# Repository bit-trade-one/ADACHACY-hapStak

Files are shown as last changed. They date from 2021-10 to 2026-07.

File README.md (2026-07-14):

# ADCHACY-hapStak

タイトル画像のURLを右のカッコに  
「触感デバイス開発/体感モジュール“hapStak“」は振動アクチュエーターと  
駆動回路がセットになった、振動による触感再現を手軽に扱うためのモジュール。  
フォスター電機が開発した最新のアクチュエーター「FOSTER ACOUSTICHAPTIC®」を採用、  
従来のモジュールにはない「広域振動」「低遅延」「静粛性」の3拍子併せ持った  
万能アクチュエーターとして様々な触感を生み出します。

## [製品の詳細はこちら](https://bit-trade-one.co.jp/hapstak/) 

## [Q&A](https://github.com/bit-trade-one/ADACHACY-hapStak/blob/master/FAQ.md)
　　
# デジタル版　
  

M5StackAtomや、ArduinoMKRZeroからのI2S信号により直接モジュールを駆動する事ができるため、  
コンパクトなデバイス作成が可能です。木製の組立ボードも付属。  

>ご注意！   デジタル版  
>本製品のご使用には別売のマイコンボード及びプログラミング用のPC,更にそれらへの基本的な知識が必要です。
>M5StackAtom端子とArduinoMKRZero端子は排他となり同時に接続できません。

## 端子情報　

  

### [M5 atom のセットアップ方法はこちら](https://qiita.com/eeldog/private/4048234a3f134ed11723)(外部サイトへ遷移）

### [M5 atom を用いた音の鳴らし方](https://qiita.com/eeldog/private/99c412695df9b6c6447c)(外部サイトへ遷移）

### [ArduinoMKRZero を用いた音の鳴らし方](https://qiita.com/eeldog/private/286d1e968b8773e05475)(外部サイトへ遷移）

### [組み立て式ケースの簡易ガイド](https://bit-trade-one.co.jp/hapstakmdfbuild/)(外部サイトへ遷移）

### [サンプルコードはこちら](https://github.com/bit-trade-one/ADACHACY-hapStak/tree/master/Samples)  

### 14種のSignal Patternsを試せる作例はこちら
- [M5Atom Matrix Arduino 1.8.19版](https://github.com/bit-trade-one/ADACHACY-hapStak/tree/master/hapStakDemo)  
- [M5Atom Matrix / S3 /S3R PlatformIO版](https://github.com/bit-trade-one/ADACHACY-hapStak/tree/master/hapStakDemo2)

### [変換ツールはこちら](https://github.com/bit-trade-one/ADACHACY-hapStak/tree/master/converter)  

### [付属ケースデータ](https://github.com/bit-trade-one/ADACHACY-hapStak/tree/master/svg)　　

### [回路図・基板図](https://github.com/bit-trade-one/ADACHACY-hapStak/tree/master/Schematics/digital)　

### [3Dプリント用ケース配布](https://github.com/bit-trade-one/ADACHACY-hapStak/tree/master/3Dprint_Case)　

### [発展的なデモソース(GNU GPLv3.0)](https://github.com/bit-trade-one/hapstak_3D_DEMO)　

---
　　
# アナログ版　
  
 
  
アンプを搭載しているため、音声信号入力のみでアクチュエータを振動させることが出来ます。　

>ご注意！アナログ版  
>本製品はアクチュエーターと駆動回路がセットになったモジュール製品です。  
>音源を再生する装置はご自身でご用意ください。USB電源端子と電池ボックスからの給電は排他となり同時使用はできません。　

## 端子情報
  　

### [回路図・基板図](https://github.com/bit-trade-one/ADACHACY-hapStak/tree/master/Schematics/analog)　

### [サンプル動画①プラコップ](https://youtu.be/OYqQZCnmybw)(外部サイトへ遷移）

### [サンプル動画②バドミントン](https://youtu.be/dnwXpK6lNK8)(外部サイトへ遷移）

---
## 作例
・[特定の方向に引っ張られているかのような錯覚を起こすサンプル](https://github.com/stake2722/HapStak_Pullusion/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) (stake2722様作)

[「ｈ.tanaka」様 /](https://x.com/hide63414/status/1664280147862884352?s=61&t=K7_oe2BjRKS2lTFRml1X2A)

---
## 製品仕様
基本仕様
 
【搭載アクチュエーター】フォスター電機 ACOUSTICHAPTIC® 639897  
【搭載アンプ】デジタル版：NS4168  
【対応マイコンボード】M5StackAtom/Lite/Matrix/Echo(Echo付属スピーカー発音有）、ArduinoMKRZero  
【必要電力】約1W   
（デジタル版:マイコンボードより供給、アナログ版:USBもしくは付属電池ボックスより供給）  
【本体重量】デジタル版：約 45g (MDF組立時）  
アナログ版：基板 約5g、アクチュエーター 約30g  
【本体サイズ】デジタル版：約 W72×H20×D30mm (MDF組立時）  
アナログ版：約 W25×H10×D25mm （基板のみ、電池ボックス及びアクチュエーターを除く）  
【付属品】MDF Stacking Board（デジタル版のみ）、電池ボックス（アナログ版のみ）、保証書  
【パッケージサイズ】F-8 チャック袋梱包　約170*120*20mm  
【使用温度】 0 ～ 40℃（結露なきこと）  
【保証期間】1年間  
【生産国】Made in Japan

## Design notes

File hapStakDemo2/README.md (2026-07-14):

# ADACHACY - hapStakDemo

触感デバイス開発モジュール **hapStak** と M5Stack ATOMシリーズの構成で、14種のSignal Patterns（触覚振動）を試せるデモプログラムです。

本バージョンは旧Arduino IDE版（M5Atomライブラリ + ESP32ボード1.0.6）を全面的に更新したものです。
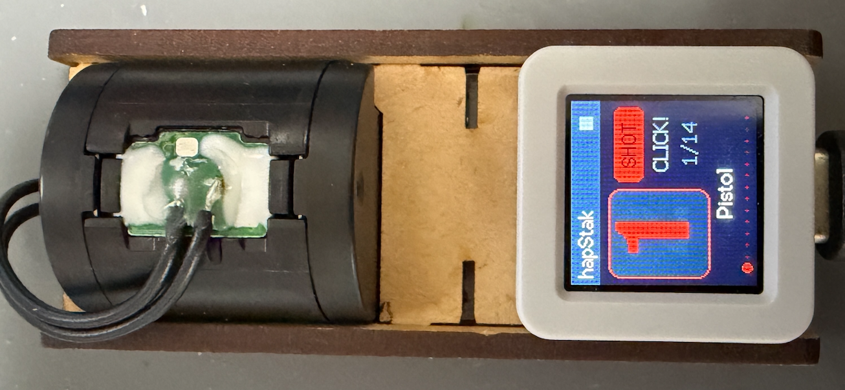
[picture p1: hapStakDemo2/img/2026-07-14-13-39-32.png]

## 対応ハードウェア

| ボード | SoC | 表示 | ビルド環境名 |
|---|---|---|---|
| ATOM Matrix | ESP32 | 5x5 LEDマトリクス | `m5stack-atom` |
| AtomS3 | ESP32-S3 | 128x128 LCD GUI | `m5stack-atoms3` |
| AtomS3R | ESP32-S3 | 128x128 LCD GUI | `m5stack-atoms3` |

AtomS3とAtomS3R（IMU: MPU6886 / BMI270 の違い等）は、**M5Unifiedが実行時に自動判別**するため同一ファームウェアで動作します。

## 旧版からの変更点

- **PlatformIOプロジェクト化** — Arduino IDEのバージョン固定（ESP32 1.0.6 / M5Atom 0.0.9）が不要になりました
- **M5Unified対応** — ATOM Matrix / AtomS3 / AtomS3R を1つのコードでサポート
- **WAVデータのフラッシュ埋め込み再生（PROGMEM）** — SPIFFSへの書き込みが不要になり、旧版の「`WRITEFILES 1`で書き込み→`0`に戻して再書き込み」という2段階手順を撤廃。**1回の書き込みだけで動作します**
- **AtomS3/S3R用のLCD GUI** — トラック番号・カテゴリ・信号名・再生アニメーションを表示

## ファイルリスト

- `README.md` — 本ドキュメント
- `TESTING.md` — テスト一覧（期待動作・各Signalの意味の一覧）
- `LICENSE.txt` — ライセンス条項（GPLv3）
- `hapStakDemo Instruction.pdf` — 使用方法（旧版の手順書。操作方法の参考）
- `platformio.ini` — PlatformIOプロジェクト設定
- `src/main.cpp` — メインプログラム
- `src/ui.h` / `src/ui_matrix.cpp` / `src/ui_lcd.cpp` — 表示処理（LEDマトリクス / LCD GUI）
- `src/AudioGeneratorWAVRepeatable.{h,cpp}` — シームレスループ再生対応WAVジェネレータ
- `src/wav/*.h` — 振動波形データ（C配列化されたWAV）

## ビルドとインストール

[PlatformIO](https://platformio.org/)（VSCode拡張 または CLI）が必要です。ライブラリ（M5Unified / ESP8266Audio / FastLED）は初回ビルド時に自動でインストールされます。

```sh
# AtomS3 / AtomS3R
pio run -e m5stack-atoms3 -t upload

# ATOM Matrix
pio run -e m5stack-atom -t upload

# シリアルモニタ (115200bps)
pio device monitor
```

> **Note (AtomS3/S3R):** 書き込みに失敗する場合は、本体側面のリセットボタンを緑色LEDが点灯するまで（約2秒）長押ししてダウンロードモードに入れてから書き込んでください。

## 使用方法

1. hapStakモジュールをATOM裏面のソケットに接続し、Atom TailBatまたはUSB-Cから給電すると起動音が鳴りStandby状態になります（起動画面 → Signal 1の表示）。
2. Trigger Switch（ATOM Matrix: 画面パネル / AtomS3系: 画面）で操作します。

| 操作 | 動作 |
|---|---|
| 短押し（クリック） | One Shot: 振動を1回発振 / LOOP: 再生・停止の切り替え（フェードイン・アウト付き） |
| 本体を振る（約3G以上） | Swing: 振動を1回発振 |
| 長押し（約0.3秒） | 次のSignalへ切り替え |
| 長押し（約1秒） | Action Categoryごとにスキップ（One Shot → Swing → LOOP → …） |
| トリプルクリック | Signal 1に戻る |

### 画面表示

**ATOM Matrix（5x5 LED）**
- Signal番号を表示（色はAction Category: One Shot=赤 / Swing=緑 / LOOP=青）
- 右下LED: 再生中（白点灯）
- 右上LED: エラー（赤点灯）

**AtomS3 / AtomS3R（LCD GUI）**
- 起動時: スプラッシュ画面（機種名を自動表示）
- Signal番号（カテゴリ色）／カテゴリチップ（SHOT / SWING / LOOP）
- 信号名（Pistol、Heart Beat等）とトリガーヒント（CLICK! / SHAKE! / REPEAT）
- 14トラックのポジションドット、再生中はイコライザ風アニメーション

## Signal Patterns 仕様

全波形とも **モノラル / 8bit PCM / 8kHz** のWAVデータです。起動音のみ16kHzです。

### One Shot（クリックで1回発振・赤）

| No. | 信号名 | 長さ | データ |
|---|---|---|---|
| 1 | Pistol | 1.5秒 | `file07.h` |
| 2 | Machine Gun | 2.0秒 | `file08.h` |
| 3 | Bazooka | 3.3秒 | `file09.h` |

### Swing（振ると1回発振・緑）

| No. | 信号名 | 長さ | データ |
|---|---|---|---|
| 4 | Tennis | 0.2秒 | `file10.h` |
| 5 | Wooden Bat | 1.4秒 | `file11.h` |
| 6 | Iron Bat | 0.9秒 | `file12.h` |
| 7 | Sword Slash (Blank) | 0.5秒 | `file13.h` |
| 8 | Sword Slash (Object) | 0.3秒 | `file14.h` |

### LOOP（選択中は繰り返し発振・青）

| No. | 信号名 | 長さ(1周期) | データ |
|---|---|---|---|
| 9 | Low Vibe (60Hz) | 0.1秒 | `file01.h` |
| A | Crispy Pulse | 0.08秒 | `file02.h` |
| B | Up Sweep | 0.5秒 | `file03.h` |
| C | Alpha Wave (60Hz) | 10秒 | `file04.h` |
| D | Dinosaur Walk | 1.3秒 | `file05.h` |
| E | Heart Beat | 1.8秒 | `file06.h` |

その他: 起動音 = `boot.h`（2.0秒 / 16kHz）。`file15.h` / `file16.h` はLow Vibeの複製（予備・未使用）。

波形の差し替えは、WAVファイルをC配列化した`.h`を`src/wav/`に置き、`src/main.cpp`の`trackData`テーブル（表示番号・信号名・駆動モード・ゲイン・表示色）を書き換えるだけです。

## ピンアサイン（I2S → hapStak）

hapStakモジュールはATOM裏面ソケットに接続します。AtomS3系はATOM Matrixと**物理位置互換**のGPIOを自動選択します。

| 信号 | ATOM Matrix | AtomS3 / AtomS3R |
|---|---|---|
| BCK | G19 | G6 |
| LRCK | G33 | G8 |
| DATA | G22 | G5 |

## 使用ライブラリ

- [M5Unified](https://github.com/m5stack/M5Unified) — ボード自動判別・LCD・IMU・ボタン
- [ESP8266Audio](https://github.com/earlephilhower/ESP8266Audio) by @earlephilhower — I2S WAV再生（Thanks to @earlephilhower!）
- [FastLED](https://github.com/FastLED/FastLED) — ATOM MatrixのLED表示

## ライセンス

GPLv3 — 詳細は`LICENSE.txt`を参照してください。
Copyright (C) 2021 Foster Electric Co., Ltd.

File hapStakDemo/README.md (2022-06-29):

# ADCHACY - hapStakDemo インストール方法

## はじめに
本作例では、触感デバイス開発モジュールとM5Atom Matrixの構成で、14種のSignal Patternsを試すことができます。

## ファイルリスト
- README.md [本ドキュメント]
- LICENSE.txt[ライセンス条項]
- hapStakDemo Instruction.pdf［使用方法］
- hapStakDemo.ino[サンプルプログラム]
- AudioGeneratorWAVRepeatable.cpp[サンプルプログラム]
- AudioGeneratorWAVRepeatable.h[サンプルプログラム]
- wav/*.h[サンプル音源]

## 前提条件
本作例の動作を確認済みの環境は以下になります。
- Arduino IDE 1.8.19（Windows版）
- ESP32ボードライブラリ 1.0.6
- M5Atomライブラリ 0.0.9
- [ESP8266Audio 1.9.5](https://github.com/earlephilhower/ESP8266Audio/tree/1.9.5) [@earlephilhower氏の
ESP8266Audioライブラリを使用させていただきました。]<BR>
Thanks to  @earlephilhower, author of the ESP8266Audio library.

## 注意事項
　2022年6月現在、最新のArduinoのライブラリでは本サンプルソフトの正常なビルドおよび動作が確認できておりません。指定のバージョンのライブラリをインストールした環境を推奨します。

## インストール方法　
- ボードマネージャのインストール<BR>
「ESP32 by Espressif Systems バージョン1.0.6」をインストールします。
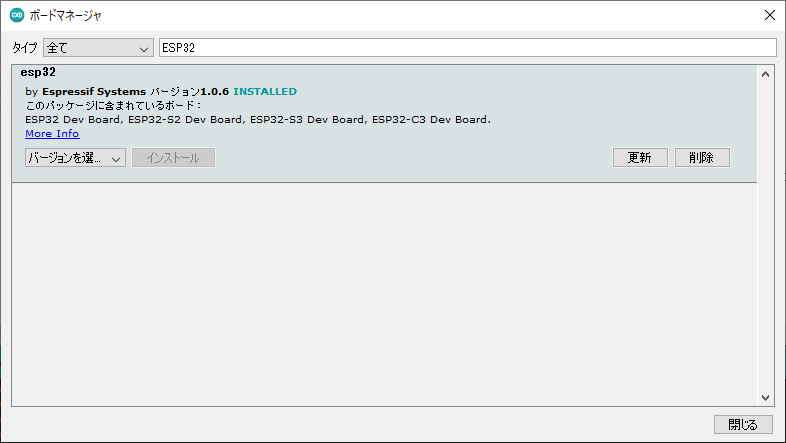
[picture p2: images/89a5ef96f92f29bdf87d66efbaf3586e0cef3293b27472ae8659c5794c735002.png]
  

- M5Atomライブラリのインストール<BR>
「ツール」「ライブラリを管理」からライブラリマネージャを開き、「M5Atom by M5Stack バージョン0.0.9」をインストールします。
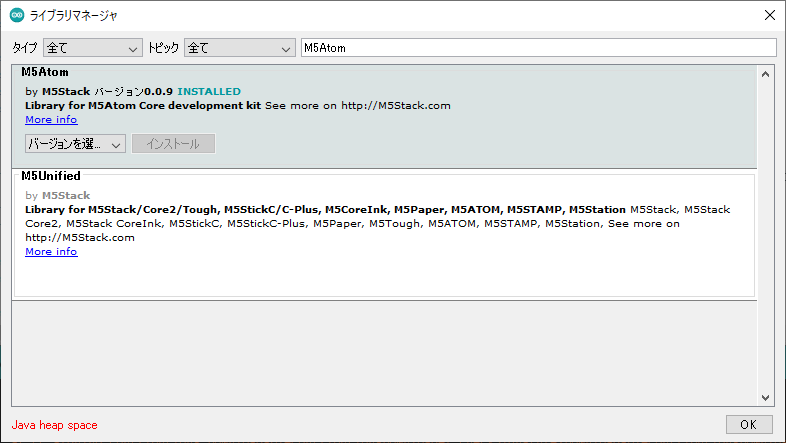
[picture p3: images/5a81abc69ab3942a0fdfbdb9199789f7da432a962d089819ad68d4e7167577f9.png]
  

- ESP8266Audioライブラリ<BR>
GitHubからzip形式でダウンロード後、Arduino IDEの「スケッチ」「ライブラリをインクルード」「.ZIP形式のライブラリをインストール」を選択し、ダウンロードしたzipファイルを指定します。
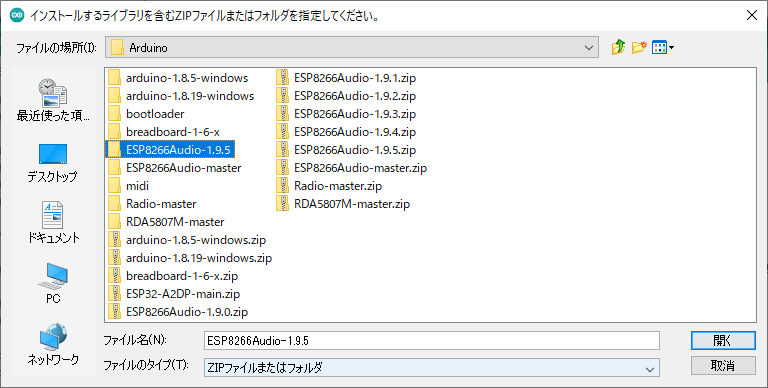
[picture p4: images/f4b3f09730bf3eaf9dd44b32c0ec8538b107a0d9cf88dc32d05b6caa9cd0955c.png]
  

- hapStakDemo<BR>
Arduino IDEの「ファイル」「開く」から予めダウンロード済みの「hapStakDemo.ino」を指定します。
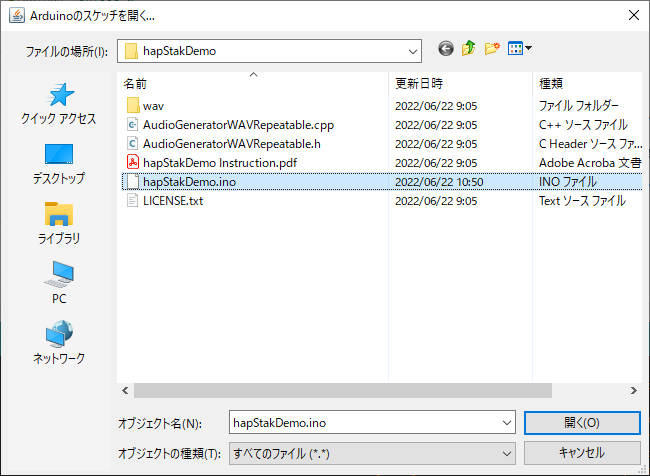
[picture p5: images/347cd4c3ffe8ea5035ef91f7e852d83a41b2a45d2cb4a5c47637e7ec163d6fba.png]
  

- Arduino IDEの設定<BR>
「ツール」メニューから「ボード」は「M5Stack-ATOM」、「シリアルポート」は接続したCOM番号を指定します。
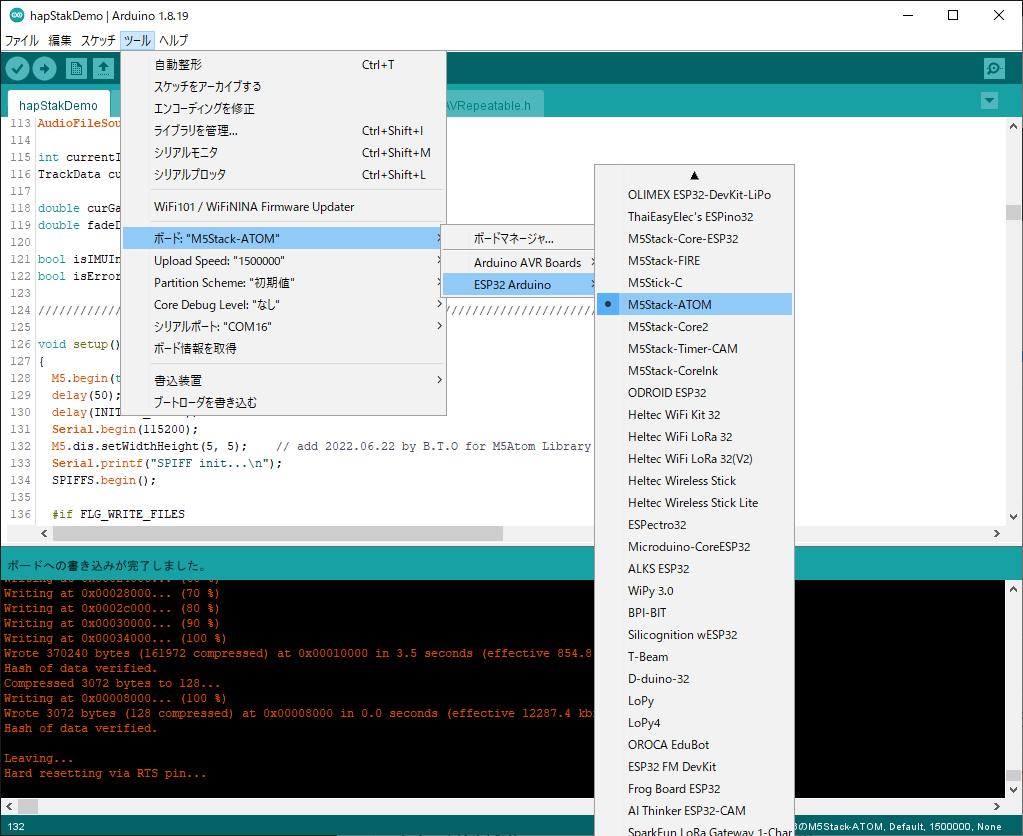
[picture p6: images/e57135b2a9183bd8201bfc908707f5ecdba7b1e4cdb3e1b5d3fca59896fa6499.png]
  

- ビルドとインストール<BR>
「スケッチ」「マイコンボードに書き込む」からビルドとインストールを実施します。以降は、[HapStackDemo Instruction](https://github.com/bit-trade-one/ADACHACY-hapStak/blob/master/hapStakDemo/hapStakDemo%20Instruction.pdf)に従ってください。

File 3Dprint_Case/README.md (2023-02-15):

# filelist

- README.md
  - 本ファイル
- hapStak_3D_20220802 v1.stl
  - STLファイル。Github上でプレビュー可能です
- hapStak_3D_20220802.stp
  - STEPファイル

# 本体写真







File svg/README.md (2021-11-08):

##  [MDFケースの簡易組立ガイドはこちら](https://bit-trade-one.co.jp/hapstakmdfbuild/)(外部サイトへ遷移）

## 展開図 
### [ADACHA_digital_Housing.png](https://github.com/bit-trade-one/ADACHACY-hapStak/blob/master/svg/ADACHA_digital_Housing.png)　 
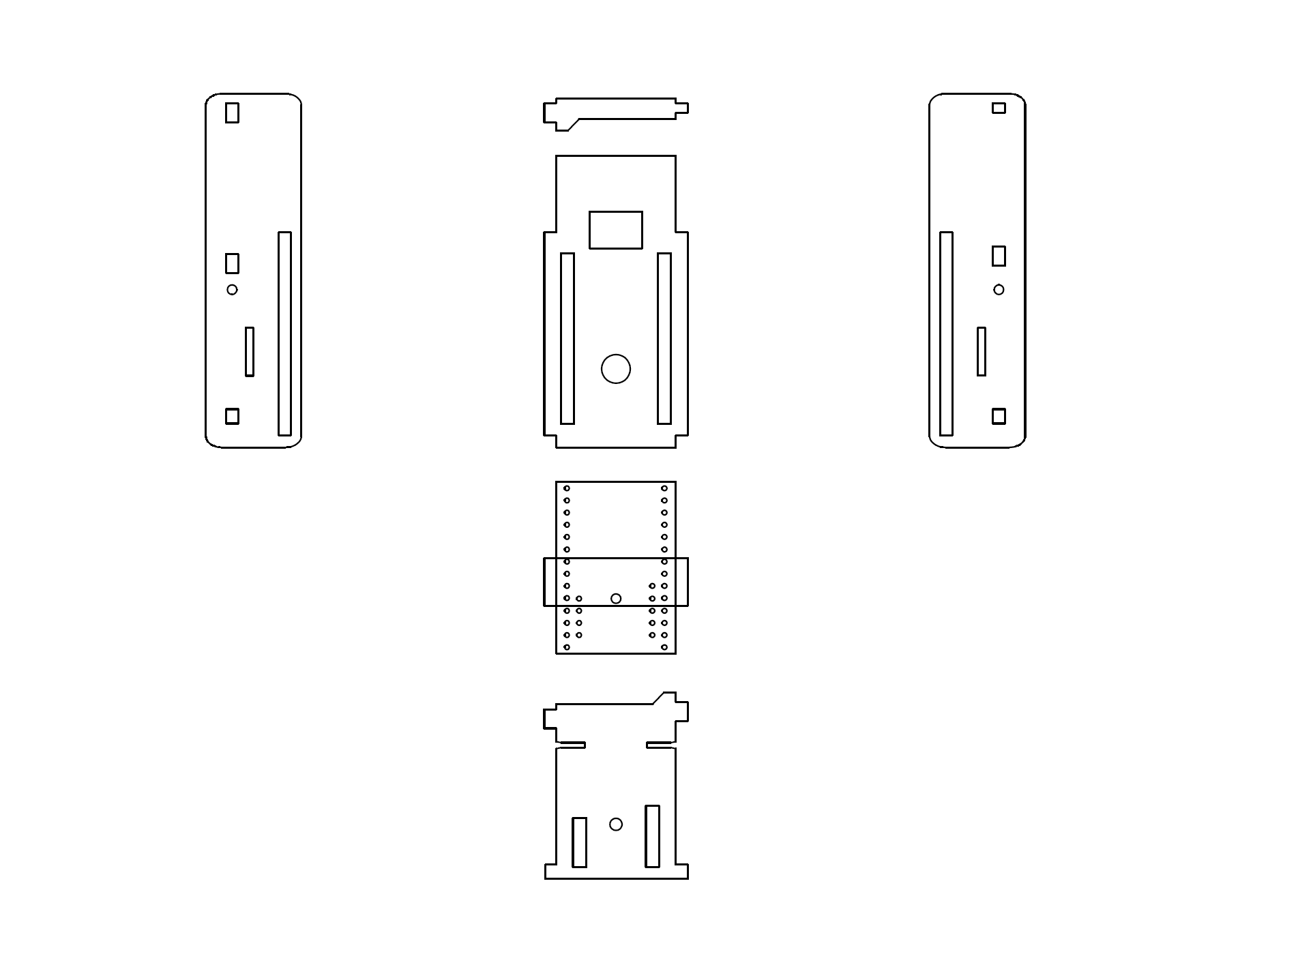
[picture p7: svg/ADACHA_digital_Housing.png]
  
  
## svgが必要な場合はこちらをお使いください。  
###  [hapStak_v100L3c2p5k5L.svg](https://github.com/bit-trade-one/ADACHACY-hapStak/blob/master/svg/hapStak_v100L3c2p5k5L.svg)

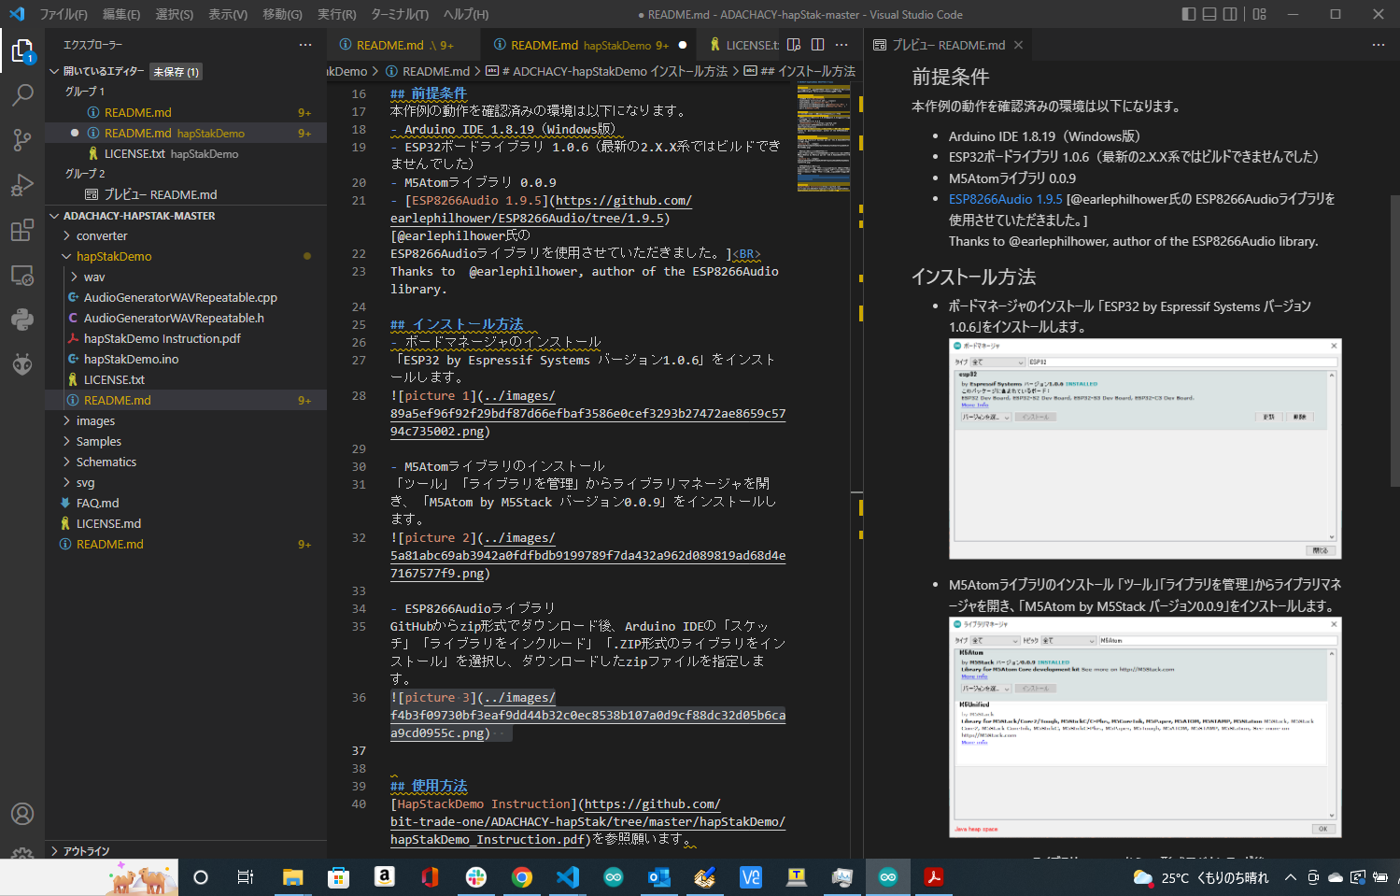
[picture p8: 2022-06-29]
images/1d6149066ba7110dcfcefb8596d89483c0a5b277a1b3aa42a23163144236d40b.png

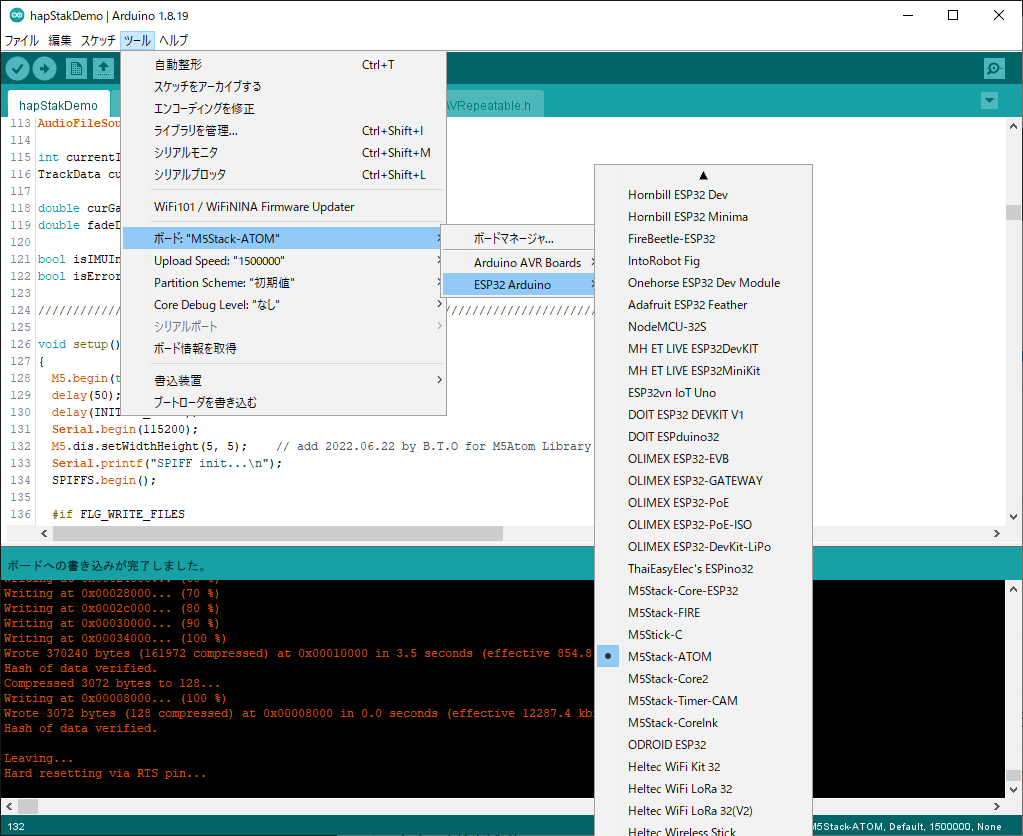
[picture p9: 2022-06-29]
images/1a6300dcdf5a7bfe7124d6cb19e79782b34bdc88744a28cd118b9b9b80bcd5b1.png

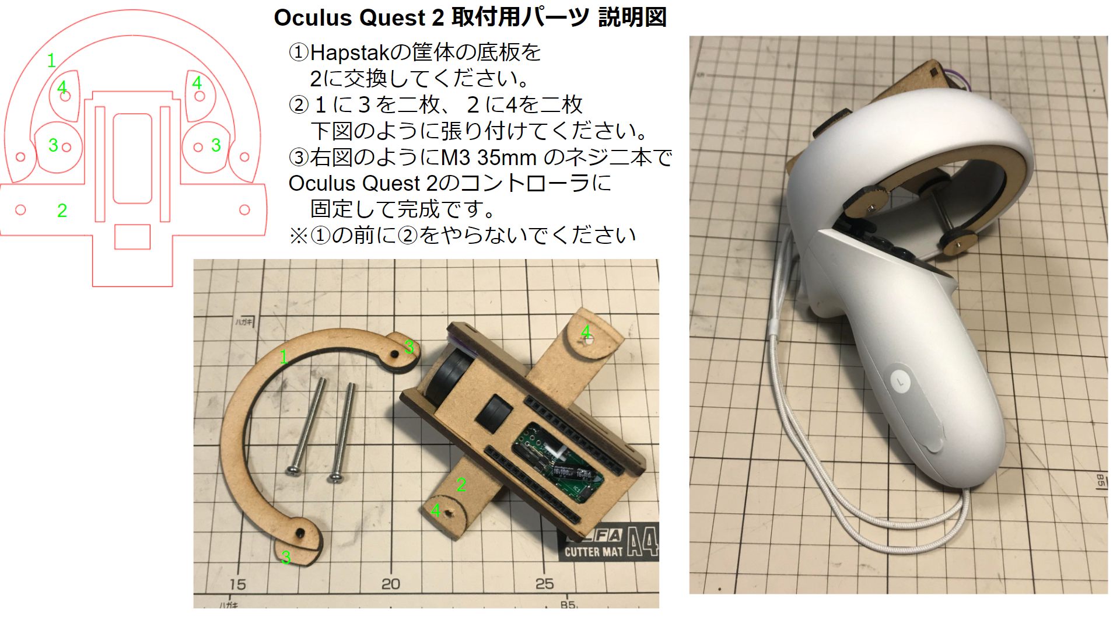
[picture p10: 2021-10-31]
svg/Oculus Quest 2 取付用パーツ 説明図.png

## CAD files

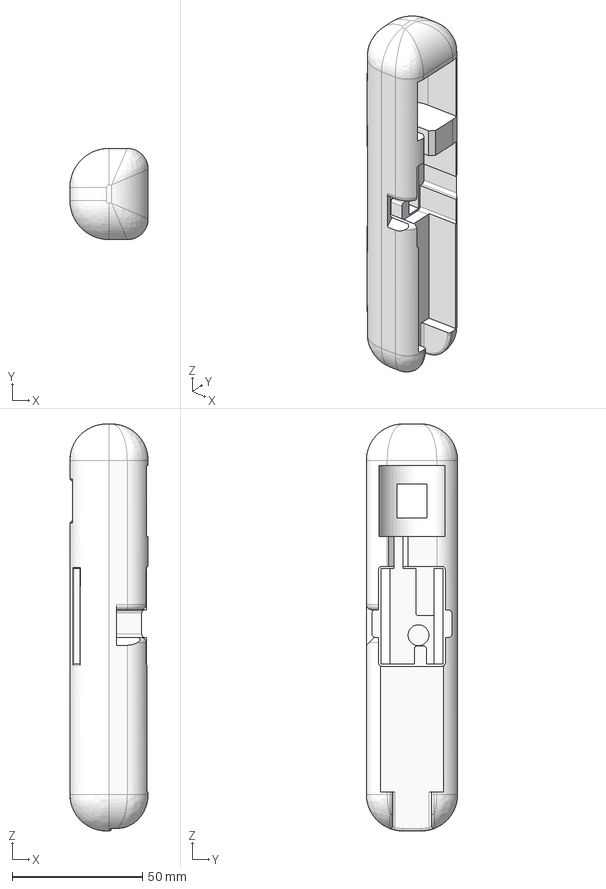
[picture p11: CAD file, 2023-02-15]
3Dprint_Case/hapStak_3D_20220802.stp
30.0 x 35.0 x 156.0 mm

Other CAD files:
3Dprint_Case/hapStak_3D_20220802 v1.stl

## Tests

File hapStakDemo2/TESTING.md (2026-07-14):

# hapStakDemo テスト一覧

各テストの「期待される動作」と一致すればOKです。
シリアルログで確認する場合は `pio device monitor`（115200bps）を使います。

対応機種: ATOM Matrix / AtomS3 / AtomS3R（表示の読み替えは[表示の見方](#5-表示の見方)を参照）

---

## 1. 起動テスト

| # | 手順 | 期待される動作 |
|---|---|---|
| 1-1 | USB-CまたはAtom TailBatから給電する | 起動画面（Matrix: 全LED白点灯 / S3系: hapStakロゴ画面）が出る |
| 1-2 | そのまま待つ | 起動音（約2秒）がhapStakから鳴る |
| 1-3 | 起動音の終了後 | 赤い「**1**」が表示される（= Signal 1選択、無音・無振動で待機） |
| 1-4 | シリアルログ確認（任意） | `IMU: OK` と `SelectTrack:1 Pistol` が出る。`IMU: not found` はNG（Swing不可・エラー表示点灯） |

## 2. Signal一覧と正解動作

「音の意味」= その振動が何を再現しているか。触った/持った手に伝わる感触で確認します。

### One Shot（赤表示・クリックで発振）

**正解動作**: ボタンを**押した瞬間**に1回振動。押すたびに鳴る。振っても鳴らない。

| No. | 名前 | 音（振動）の意味 | 長さ |
|---|---|---|---|
| 1 | Pistol | ピストルの発砲の反動 | 約1.5秒 |
| 2 | Machine Gun | マシンガンの連射の反動 | 約2.0秒 |
| 3 | Bazooka | バズーカ砲の発射 | 約3.3秒 |

### Swing（緑表示・振ると発振）

**正解動作**: 本体を**鋭く振った瞬間**に1回振動。鳴っている間と鳴り終わって0.3秒間は、振っても反応しない（連続発振防止）。クリックでは鳴らない。

| No. | 名前 | 音（振動）の意味 | 長さ |
|---|---|---|---|
| 4 | Tennis | テニスラケットの打球の衝撃 | 約0.2秒 |
| 5 | Wooden Bat | 木製バットの打球 | 約1.4秒 |
| 6 | Iron Bat | 金属バットの打球 | 約0.9秒 |
| 7 | Sword Slash (Blank) | 刀の素振り（空を斬る） | 約0.5秒 |
| 8 | Sword Slash (Object) | 刀で物を斬った手応え | 約0.3秒 |

### LOOP（青表示・自動で繰り返し）

**正解動作**: そのSignalを**選択した瞬間から**フェードインで自動再生され、繰り返し続ける。クリックするとフェードアウトして停止、もう一度クリックすると再開。

| No. | 名前 | 音（振動）の意味 | 1周期 |
|---|---|---|---|
| 9 | Low Vibe (60Hz) | 60Hzの低い連続振動 | 0.1秒 |
| A | Crispy Pulse | カリカリと弾ける短いパルス | 0.08秒 |
| B | Up Sweep | 低→高へ上昇するスイープ | 0.5秒 |
| C | Alpha Wave (60Hz) | 60Hzがゆらぐ持続振動 | 10秒 |
| D | Dinosaur Walk | 恐竜が歩くような重い足音 | 1.3秒 |
| E | Heart Beat | 心臓の鼓動（ドクン、ドクン） | 1.8秒 |

## 3. 操作テスト

| # | 手順 | 期待される動作 |
|---|---|---|
| 3-1 | ボタンを約0.3秒長押し | 次のSignalへ切り替わる（1→2→…→E→1と一巡） |
| 3-2 | ボタンを約1秒長押し | 次のカテゴリの先頭へジャンプ（1〜3で実行→4、4〜8で実行→9、9〜Eで実行→1） |
| 3-3 | 素早く3回クリック（トリプルクリック） | Signal 1に戻る（クリック間隔0.25秒以内） |
| 3-4 | Signal 9〜E選択中に1回クリック | フェードアウトして停止。もう1回クリックで再開 |
| 3-5 | LOOP再生中に0.3秒長押し | 現在の再生が止まり、次のSignalへ切り替わる |

## 4. Swing詳細テスト（Signal 4〜8）

| # | 手順 | 期待される動作 |
|---|---|---|
| 4-1 | 手首のスナップを効かせて鋭く振る | 1回だけ振動する（鳴りっぱなしにならない） |
| 4-2 | 鳴り終わってから再度振る | もう1回鳴る |
| 4-3 | 机に置いたまま・ゆっくり動かす | 鳴らない（閾値3G未満） |
| 4-4 | シリアルログ確認（任意） | 1秒ごとに `accel peak: x.xx G` が出る。静止時は約1.00、振った瞬間に3.00超え |

振っても鳴らない場合: シリアルの `accel peak` が3.00に届いていなければ、振り方が弱いか閾値が高すぎです（`src/main.cpp` の `ACCEL_THRESHOLD` を2.0程度に下げて調整可）。

## 5. 表示の見方

### ATOM Matrix（5x5 LED）

- 数字は**左4列**に表示。色 = カテゴリ（赤=One Shot / 緑=Swing / 青=LOOP）
- **右下**: 再生中のみ白点灯（LOOP選択中はほぼ点きっぱなしで正常）
- **右上**: エラー時のみ赤点灯（**常時消灯が正解**。点灯したらシリアルログを確認）
- 左上に数字と無関係な点灯が居座る場合は表示ずれ（既知の対策済み事象。再発したら報告を）

### AtomS3 / AtomS3R（LCD）

- 大きな数字（カテゴリ色）+ カテゴリチップ（SHOT/SWING/LOOP）+ 信号名
- ヘッダ右: 再生中はイコライザアニメーション、停止中はグレーの■
- ヘッダに赤丸「!」が出たらエラー（常時非表示が正解）
- 下部のドット: 現在のSignal位置（14個中）

## 6. 機種またぎテスト（任意）

| # | 手順 | 期待される動作 |
|---|---|---|
| 6-1 | 同じhapStakをAtomS3/S3Rに付け替えて起動 | 書き込み環境を`m5stack-atoms3`にするだけで同一動作（起動画面に機種名表示） |
| 6-2 | AtomS3Rで起動 | スプラッシュに「AtomS3R」と表示され、IMU（BMI270）でSwingが動く |

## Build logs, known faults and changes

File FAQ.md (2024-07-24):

# ADACHACY-hapStakよくある質問

# 共通

## Q.振動アクチュエータの詳細を教えて下さい
### A.フォスター電機殿のデータシートをご覧ください
https://www.foster.co.jp/products/vibration_actuator/  
フォスター電機 ACOUSTICHAPTIC® 639897が使用している製品です。  

----

# デジタル版 

## Q.notext
 
### A.notext

----

# アナログ版 

## Q.モノラル音源とステレオ音源で振動に違いがありますか

### A.音源内容によりモノラル音源とステレオ音源で振動に違いが出ます

本製品はステレオの入力音源からL/R切り替えジャンパで使用する信号を選択し、選んだ片方の音源を増幅させ振動アクチュエータを駆動させます。

## Q.出力端子のどちらが+ですか？

### A.画像をご参照願います


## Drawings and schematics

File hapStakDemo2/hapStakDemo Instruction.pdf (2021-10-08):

■ Demo Instruction | ■General View

■ Signal patterns

1. Atom TailBatもしくはUSB-Cケーブルより給電すると起動音が発生し、 Standby状態になります。（LED全点灯白 → 1の表示）
2. 下表のAction Categoryに従い触覚信号が駆動します。
3. Trigger Switchを短く(0.3sくらい)長押しするとSignal を切り替えできます。
4. Trigger Switchを長く(1sくらい)長押しするとAction Categoryごとに Skipできます。
5. 選択信号のガイドとして、LEDの表示を参照ください。
6. 給電を停止すると停止します。 (LED 消灯)

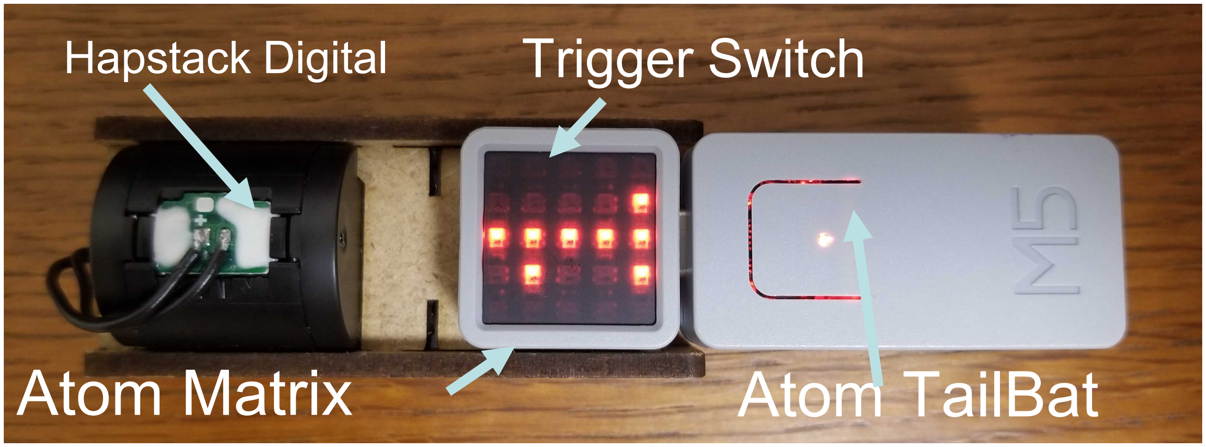
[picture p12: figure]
Trigger Switch; Atom TailBat; Hapstack Digital; Atom Matrix

No, | Description | Action | LED表示
1 | Pistol | One Shot (シングルクリックで一回発振) | 1
2 | Machine Gun | 〃 | 2
3 | Bazooka | 〃 | 3
4 | Tennis | Swing（振ると一回発振） | 4
5 | Wooden bat | 〃 | 5
6 | Iron Bat | 〃 | 6
7 | Sword Slash (Blank) | 〃 | 7
8 | Sword Slash (Object) | 〃 | 8
9 | Low Vibe (60Hz) | LOOP (Signal選択中は繰り返し発振) | 9
A | Crispy Pulse | 〃 | A
B | Up Sweep | 〃 | B
C | α Wave (60Hz) | 〃 | C
D | Dinosaur Walk | 〃 | D
E | Heart Beat | 〃 | E

# hapStakDemo Instruction

# hapStakDemo Instruction

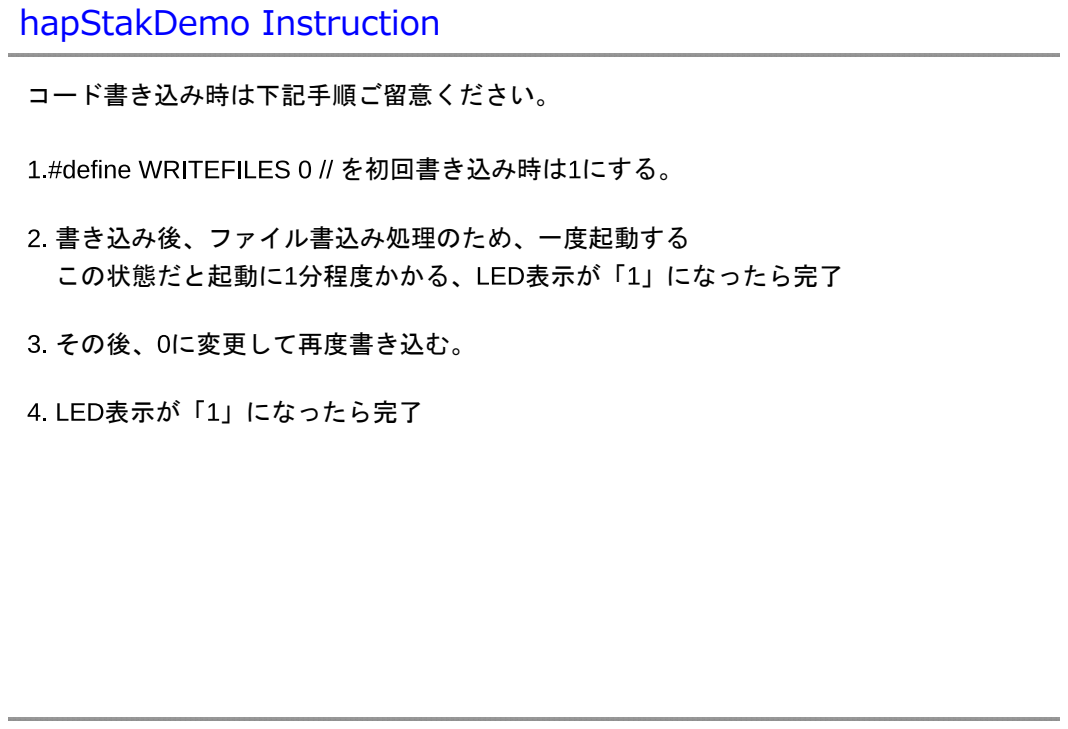
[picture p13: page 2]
コード書き込み時は下記手順ご留意ください。; を初回書き込み時は にする。; この状態だと起動に 分程度かかる、; 表示が「 」になったら完了; その後、 に変更して再度書き込む。

書き込み後、ファイル書込み処理のため、一度起動する

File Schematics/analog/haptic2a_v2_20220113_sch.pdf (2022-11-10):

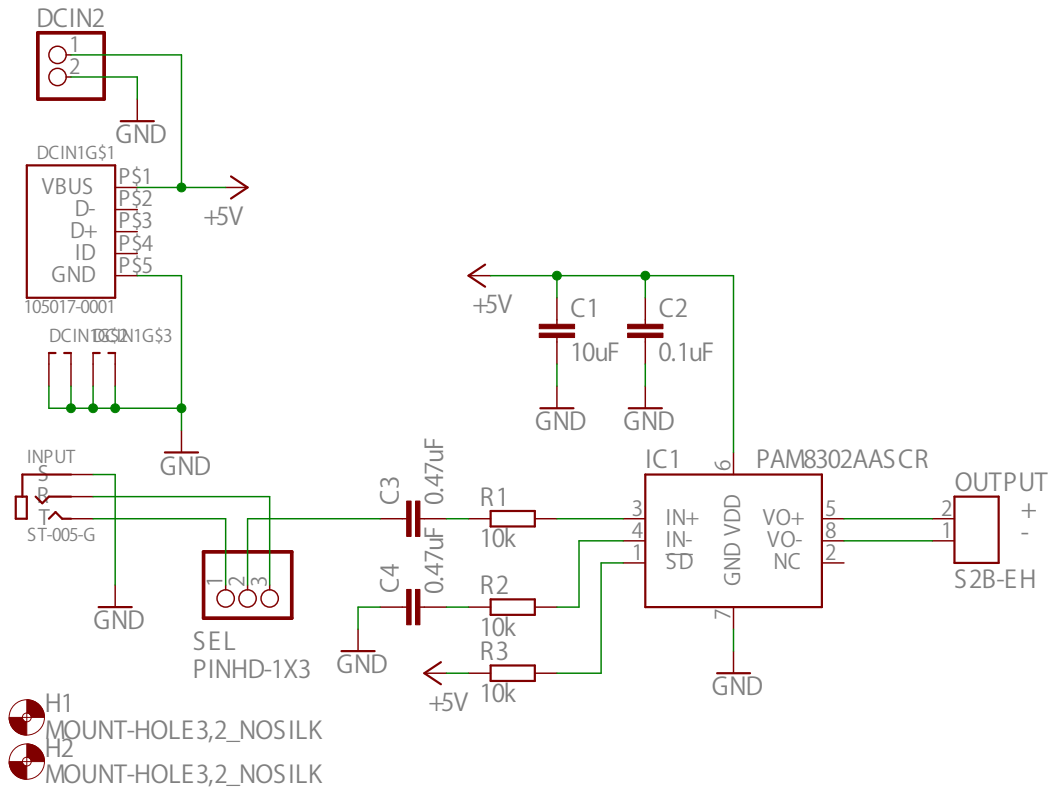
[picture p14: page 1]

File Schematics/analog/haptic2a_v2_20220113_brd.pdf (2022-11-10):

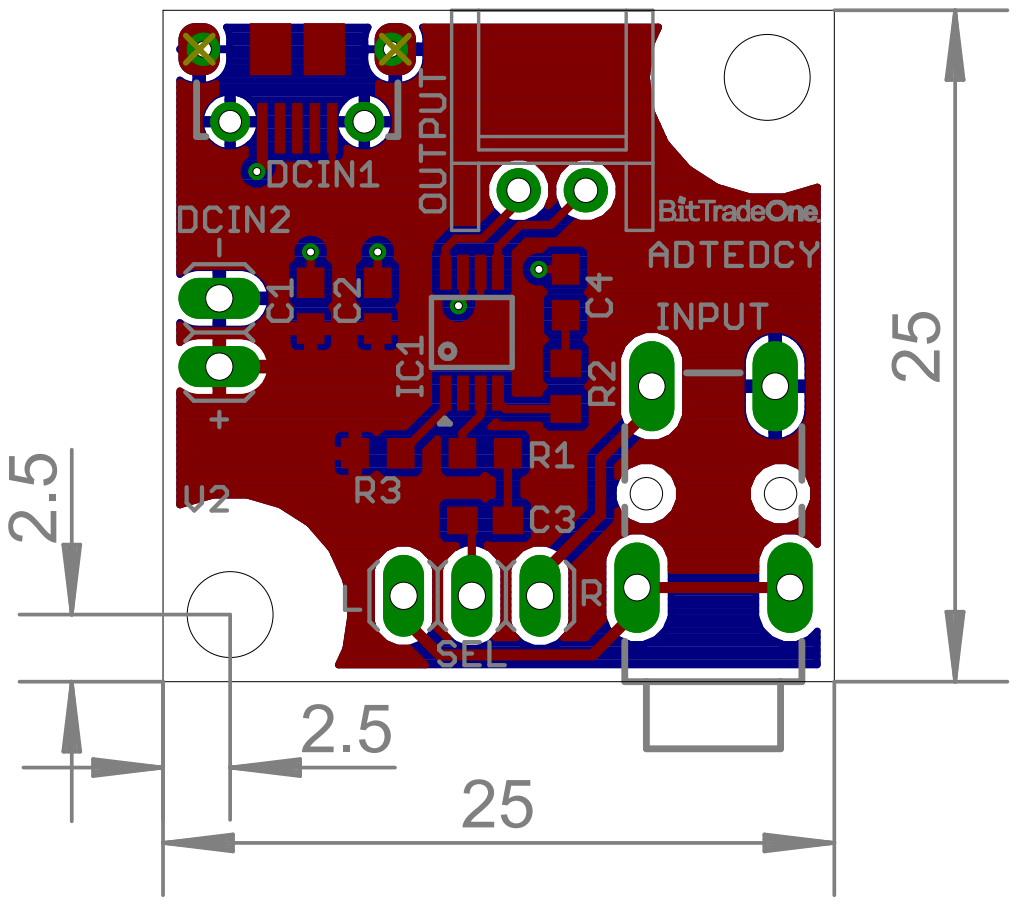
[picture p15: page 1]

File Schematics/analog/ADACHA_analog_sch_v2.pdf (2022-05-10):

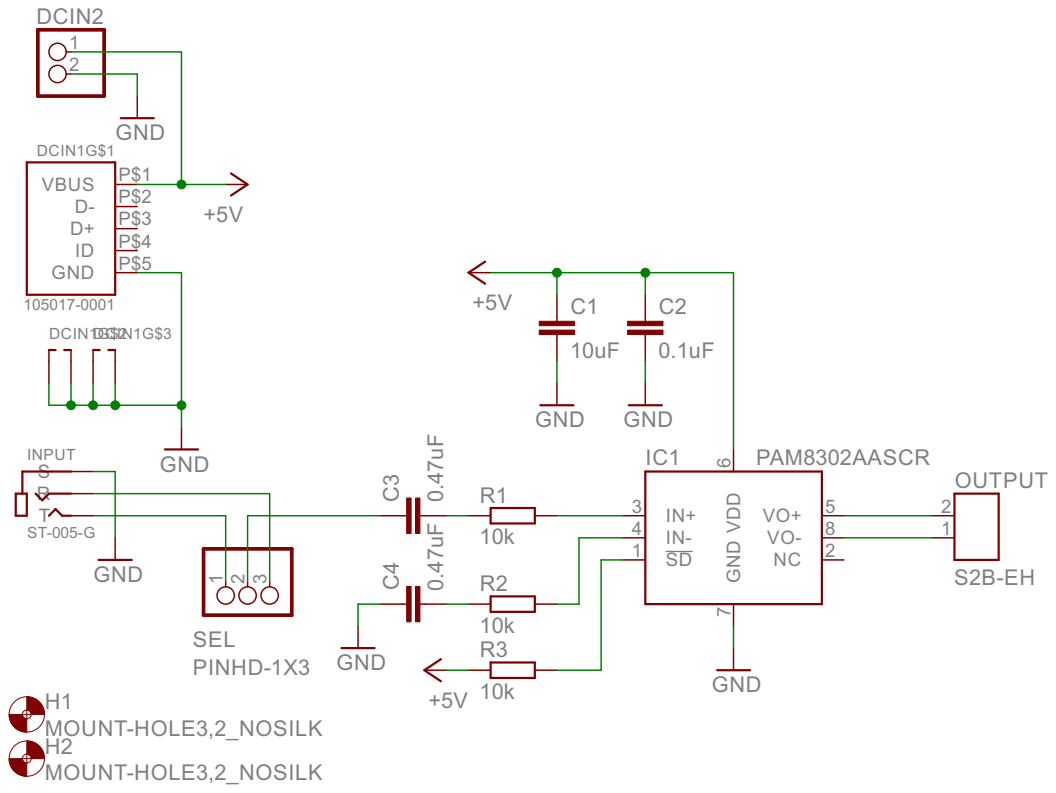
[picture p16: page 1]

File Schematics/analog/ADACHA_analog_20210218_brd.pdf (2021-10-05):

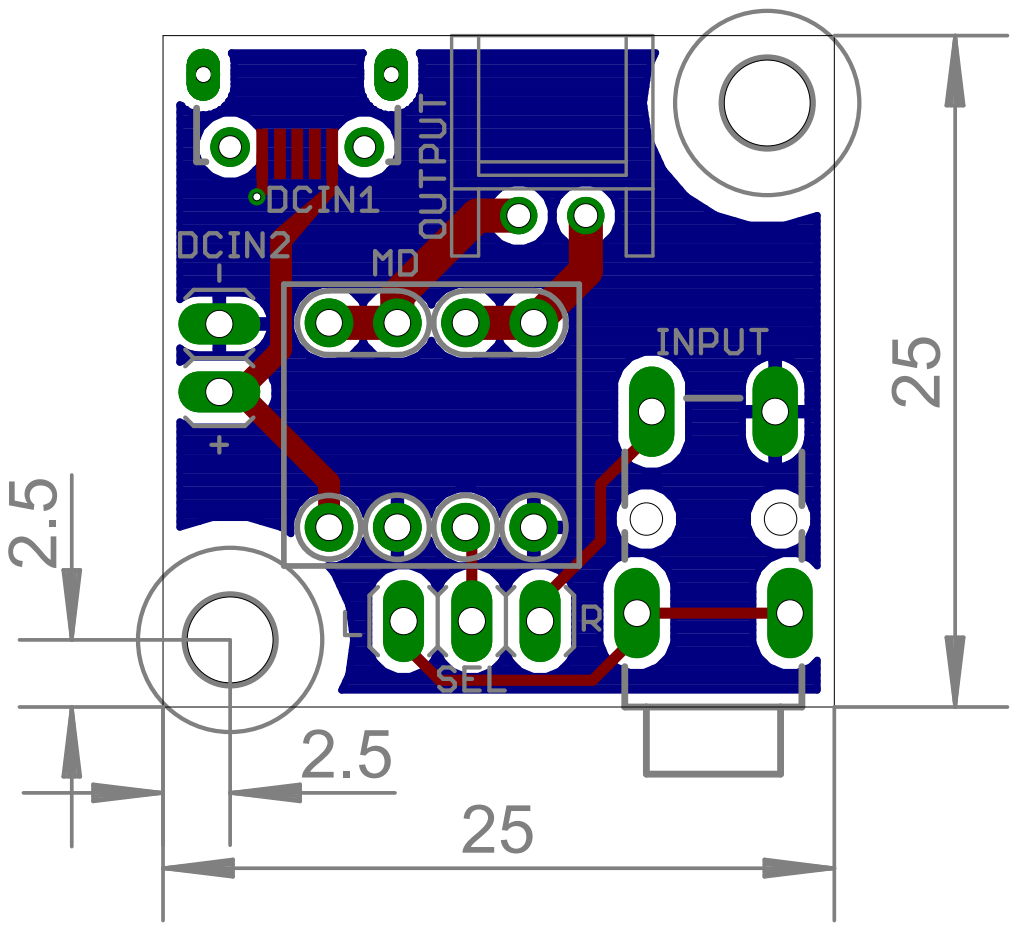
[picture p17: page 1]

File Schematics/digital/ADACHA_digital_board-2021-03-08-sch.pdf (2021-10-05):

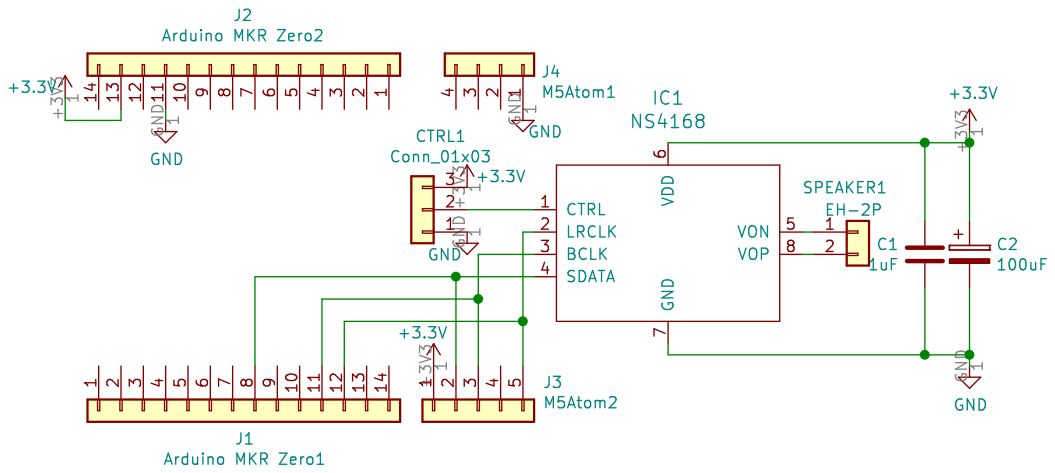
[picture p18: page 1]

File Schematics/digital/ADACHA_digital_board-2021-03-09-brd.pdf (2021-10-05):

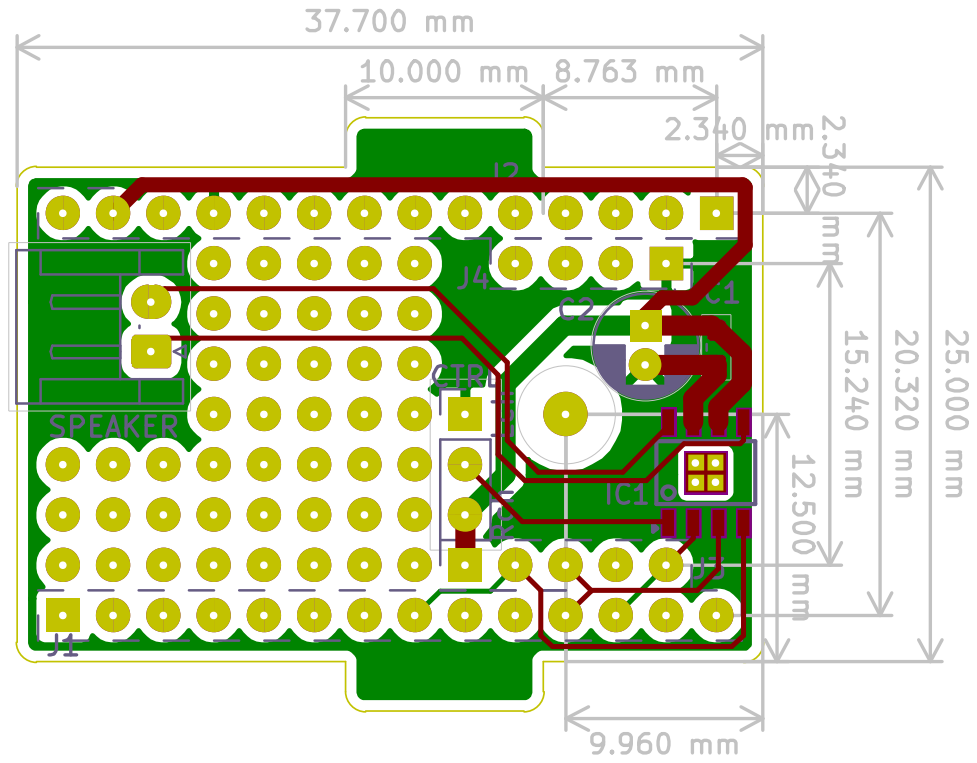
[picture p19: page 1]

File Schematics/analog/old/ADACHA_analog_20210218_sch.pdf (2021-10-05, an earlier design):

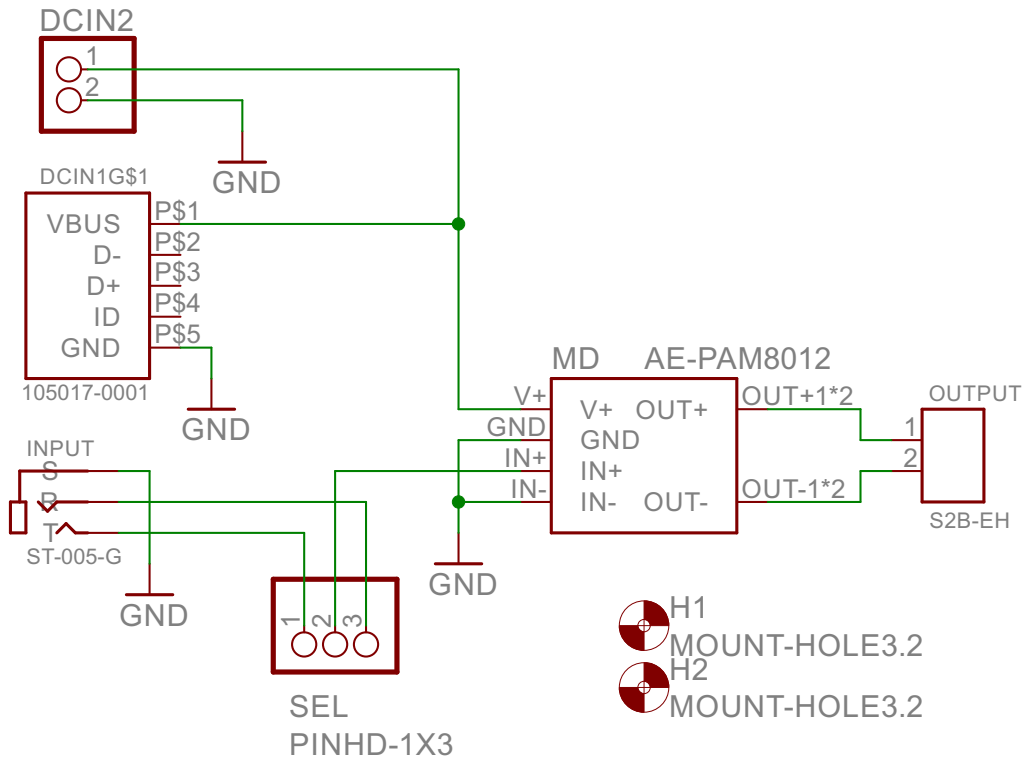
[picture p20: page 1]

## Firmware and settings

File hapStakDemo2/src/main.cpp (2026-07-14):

/*
  hapStak DemoProgram
  version 1.0

  Copyright (C) 2021 Foster Electric Co., Ltd.

  version 1.0 changes:
  - PlatformIO project
  - M5Unified (ATOM Matrix / AtomS3 / AtomS3R auto detection)
  - WAV data is embedded in flash (PROGMEM), no SPIFFS write step required
  - LCD GUI for AtomS3 / AtomS3R

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
  You should have received a copy of the GNU General Public License
  along with this program.  If not, see <http://www.gnu.org/licenses/>.
*/

#include <M5Unified.h>
#include <math.h>

#include "AudioFileSourcePROGMEM.h"
#include "AudioGeneratorWAVRepeatable.h"
#include "AudioOutputI2S.h"

#include "ui.h"

// 振動波形データ（フラッシュ埋め込み）
#include "wav/boot.h"
#include "wav/file01.h"
#include "wav/file02.h"
#include "wav/file03.h"
#include "wav/file04.h"
#include "wav/file05.h"
#include "wav/file06.h"
#include "wav/file07.h"
#include "wav/file08.h"
#include "wav/file09.h"
#include "wav/file10.h"
#include "wav/file11.h"
#include "wav/file12.h"
#include "wav/file13.h"
#include "wav/file14.h"

//////////////////////////////////////////////////////////////////////////////////////////////////////////

// hapStakモジュール(裏面ソケット)のI2Sピン
#if defined(CONFIG_IDF_TARGET_ESP32S3)
// AtomS3 / AtomS3R : ATOM Matrixと物理位置互換のピン (G19->G6, G33->G8, G22->G5)
const int CONFIG_I2S_BCK_PIN  = 6;
const int CONFIG_I2S_LRCK_PIN = 8;
const int CONFIG_I2S_DATA_PIN = 5;
#else
// ATOM Matrix
const int CONFIG_I2S_BCK_PIN  = 19;
const int CONFIG_I2S_LRCK_PIN = 33;
const int CONFIG_I2S_DATA_PIN = 22;
#endif

const float DEFAULT_GAIN = 1.0; // 振動信号のデフォルトゲイン。0.0～1.0
const float BEEP_GAIN = 0.5;    // Beep音、起動音のゲイン。0.0～1.0

const float ACCEL_THRESHOLD = 3.0;  // Swingトリガー時の閾値加速度[G]
const int SWING_COOLDOWN = 300;     // Swing再生終了後の再トリガー禁止時間[ms]（自身の振動による誤トリガー防止）

const int INITIAL_DELAY = 0;  // 動作開始前のdelay値
const int LOOP_DELAY = 5;     // メインループのdelay値

const int FADEIN_STEP = int(1000 / LOOP_DELAY); // フェードインのステップ数
const int FADEOUT_STEP = int(250 / LOOP_DELAY); // フェードアウトのステップ数

const long LONG_COUNT = int(300 / LOOP_DELAY);      // 長押しの反応時間
const long LONG_LONG_COUNT = int(900 / LOOP_DELAY); // 超長押しの反応時間
const long MULTI_COUNT = int(250 / LOOP_DELAY);     // ダブル・トリプルクリックの反応時間（クリック間隔がこれ以内なら連打と判定）

//////////////////////////////////////////////////////////////////////////////////////////////////////////

typedef struct {
  const unsigned char* data;
  size_t size;
} WavRef;

#define WAV_REF(arr) { arr, sizeof(arr) }

typedef struct {
  int dispNumber;
  WavRef wav;
  const char* name;
  int triggerMode;
  float gain;
  uint8_t dispColor[3];
} TrackData;

#define COLOR_RED { 0xFF, 0x00, 0x00 }
#define COLOR_GREEN { 0x00, 0xFF, 0x00 }
#define COLOR_BLUE { 0x00, 0x00, 0xFF }

const int BUTTON_FIRST = 0;
const int ACCEL_FIRST = 3;
const int LOOP_FIRST = 8;

const int TRACK_COUNT = 14; // 振動再生モード（トラック）の数

// トラックデータ
// LED/LCD表示の番号(0～F), 振動波形データ, 信号名, 駆動モードの種類, 再生ゲイン, 表示色
const TrackData trackData[TRACK_COUNT] = {
  // One Shot
  { 0x1, WAV_REF(file07), "Pistol",              TRIG_BUTTON, DEFAULT_GAIN, COLOR_RED },   // BUTTON_FIRST
  { 0x2, WAV_REF(file08), "Machine Gun",         TRIG_BUTTON, DEFAULT_GAIN, COLOR_RED },
  { 0x3, WAV_REF(file09), "Bazooka",             TRIG_BUTTON, DEFAULT_GAIN, COLOR_RED },
  // Swing
  { 0x4, WAV_REF(file10), "Tennis",              TRIG_SWING,  DEFAULT_GAIN, COLOR_GREEN }, // ACCEL_FIRST
  { 0x5, WAV_REF(file11), "Wooden Bat",          TRIG_SWING,  DEFAULT_GAIN, COLOR_GREEN },
  { 0x6, WAV_REF(file12), "Iron Bat",            TRIG_SWING,  DEFAULT_GAIN, COLOR_GREEN },
  { 0x7, WAV_REF(file13), "Sword Slash (Blank)", TRIG_SWING,  DEFAULT_GAIN, COLOR_GREEN },
  { 0x8, WAV_REF(file14), "Sword Slash (Object)",TRIG_SWING,  DEFAULT_GAIN, COLOR_GREEN },
  // Loop
  { 0x9, WAV_REF(file01), "Low Vibe (60Hz)",     TRIG_LOOP,   DEFAULT_GAIN, COLOR_BLUE },  // LOOP_FIRST
  { 0xA, WAV_REF(file02), "Crispy Pulse",        TRIG_LOOP,   DEFAULT_GAIN, COLOR_BLUE },
  { 0xB, WAV_REF(file03), "Up Sweep",            TRIG_LOOP,   DEFAULT_GAIN, COLOR_BLUE },
  { 0xC, WAV_REF(file04), "Alpha Wave (60Hz)",   TRIG_LOOP,   DEFAULT_GAIN, COLOR_BLUE },
  { 0xD, WAV_REF(file05), "Dinosaur Walk",       TRIG_LOOP,   DEFAULT_GAIN, COLOR_BLUE },
  { 0xE, WAV_REF(file06), "Heart Beat",          TRIG_LOOP,   DEFAULT_GAIN, COLOR_BLUE },
};

const WavRef bootWav = WAV_REF(boot);

//////////////////////////////////////////////////////////////////////////////////////////////////////////

AudioGeneratorWAVRepeatable *wav;
AudioFileSourcePROGMEM *file;
AudioOutputI2S *out;

int currentIndex = 0;
TrackData currentData;

double curGain = 0.0;   // フェードイン・アウト時のゲイン
double fadeDelta = 0.0; // フェードイン・アウト時の変化量

bool isError = false;

void AudioLoop();
void ButtonLoop();
void AccelLoop();
void DisplayLoop();
void SingleDown();
void SinglePress();
void DoublePress();
void TriplePress();
void LongPress();
void LongLongPress();
void SelectTrack(int index);
void NextTrack();
void PrevTrack();
void LoadTrack();
void LoadFile(const WavRef& ref, float gain, bool repeat);
void Play();
void Stop();
void FadePlay();
void FadeStop();

//////////////////////////////////////////////////////////////////////////////////////////////////////////

void setup()
{
  auto cfg = M5.config();
  cfg.internal_spk = false; // 内蔵スピーカー・マイクは使わない（I2SはhapStak用）
  cfg.internal_mic = false;
  M5.begin(cfg);
  Serial.begin(115200);
  delay(50);
  delay(INITIAL_DELAY);

  Serial.printf("hapStakDemo (%s)\n",
#if defined(CONFIG_IDF_TARGET_ESP32S3)
    M5.getBoard() == m5::board_t::board_M5AtomS3R ? "AtomS3R" : "AtomS3"
#else
    "ATOM Matrix"
#endif
  );

  UiInit();
  UiSplash();

  Serial.printf("WAV playback init...\n");

  audioLogger = &Serial;

  out = new AudioOutputI2S();
  out->SetPinout(CONFIG_I2S_BCK_PIN, CONFIG_I2S_LRCK_PIN, CONFIG_I2S_DATA_PIN);
  out->SetChannels(1);
  out->SetGain(DEFAULT_GAIN);
  if (!out) {
    isError = true;
    Serial.printf("I2S init FAILED!\n");
  }

  wav = new AudioGeneratorWAVRepeatable();
  if (!wav) {
    isError = true;
    Serial.printf("generator init FAILED!\n");
  }

  Serial.printf("board=%d\n", (int)M5.getBoard());
  Serial.printf("IMU: %s (type=%d)\n", M5.Imu.isEnabled() ? "OK" : "not found", (int)M5.Imu.getType());
  if (!M5.Imu.isEnabled()) {
    isError = true; // IMU未検出: Swingトリガーが使用不可
  }

  LoadFile(bootWav, BEEP_GAIN, false);
  Play();
  while (wav->loop()) { /*noop*/ }
  Stop();

  SelectTrack(0);
}

void loop()
{
  M5.update();

  AudioLoop();
  ButtonLoop();
  AccelLoop();
  DisplayLoop();

  delay(LOOP_DELAY);
}

//////////////////////////////////////////////////////////////////////////////////////////////////////////

void ButtonLoop()
{
  static unsigned long pressCnt = 0;
  static unsigned long releaseCnt = ULONG_MAX;
  static int multiCnt = 0;

  if (M5.BtnA.isPressed()) {
    if (pressCnt < ULONG_MAX) {
      pressCnt ++;
    }

    if (pressCnt == 1) {
      SingleDown();  // 押したとき
    } else if (pressCnt == LONG_COUNT) {
      LongPress();
    } else if (pressCnt == LONG_LONG_COUNT) {
      LongLongPress();
    }

    releaseCnt = 0;
  } else {
    if (releaseCnt < ULONG_MAX) {
      releaseCnt ++;
    }

    if ((pressCnt > 0) && (pressCnt < LONG_COUNT)) {
      multiCnt ++;
    }

    if (releaseCnt == MULTI_COUNT) {
      if (multiCnt == 1) {
        SinglePress();  // 離したとき
      } else if (multiCnt == 2) {
        DoublePress();
      } else if (multiCnt >= 3) {
        TriplePress();
      }
      multiCnt = 0;
    }

    pressCnt = 0;
  }
}

void SingleDown() {
  if (currentData.triggerMode == TRIG_BUTTON) {
    LoadTrack();
    Play();
  }
}

void SinglePress() {
  if (currentData.triggerMode == TRIG_LOOP) {
    if (!(wav->isRunning())) {
      LoadTrack();
      FadePlay();
    } else {
      FadeStop();
    }
  }
}

void DoublePress() {

}

void TriplePress() {
  SelectTrack(0);
}

void LongPress() {
  NextTrack();
}

void LongLongPress() {
  if (currentIndex < ACCEL_FIRST) {
    SelectTrack(ACCEL_FIRST);
  } else if (currentIndex < LOOP_FIRST) {
    SelectTrack(LOOP_FIRST);
  } else {
    SelectTrack(BUTTON_FIRST);
  }
}

//////////////////////////////////////////////////////////////////////////////////////////////////////////

void DisplayLoop()
{
  UiState st;
  st.trackIndex = currentIndex;
  st.trackCount = TRACK_COUNT;
  st.dispNumber = currentData.dispNumber;
  st.name = currentData.name;
  st.triggerMode = currentData.triggerMode;
  st.color = currentData.dispColor;
  st.playing = wav && wav->isRunning();
  st.error = isError;

  UiUpdate(st);
}

//////////////////////////////////////////////////////////////////////////////////////////////////////////

void AccelLoop()
{
  float accX = 0, accY = 0, accZ = 0;

  if (!M5.Imu.isEnabled()) {
    return;
  }

  M5.Imu.getAccel(&accX, &accY, &accZ);

  float accTotal = sqrt(accX * accX + accY * accY + accZ * accZ);

  if (currentData.triggerMode == TRIG_SWING) {
    // 加速度ピーク値のモニタ（静止時は約1.00G。0.00ならIMU読み出し異常）
    static float peak = 0.0f;
    static uint32_t lastReport = 0;
    if (accTotal > peak) { peak = accTotal; }
    if (millis() - lastReport >= 1000) {
      Serial.printf("accel peak: %.2f G\r\n", peak);
      peak = 0.0f;
      lastReport = millis();
    }

    // 再生中および再生終了直後は再トリガーしない
    // （hapStak自身の振動をIMUが拾い、鳴り続けてしまうのを防ぐ）
    static bool wasRunning = false;
    static uint32_t quietUntil = 0;
    bool running = wav && wav->isRunning();
    if (wasRunning && !running) {
      quietUntil = millis() + SWING_COOLDOWN;
    }
    wasRunning = running;
    if (running || (millis() < quietUntil)) {
      return;
    }

    if (accTotal > ACCEL_THRESHOLD) {
      LoadTrack();
      Play();
    }
  }
}

//////////////////////////////////////////////////////////////////////////////////////////////////////////

void AudioLoop()
{
  if (!wav) { return; }
  if (!(wav->isRunning())) { return; }

  if (!(wav->loop())) { // wav->loop()はリピートしない場合のみfalseを返す
    wav->stop();
  }

  if (!(wav->Repeat)) { return; }

  if (fadeDelta < 0) {  // フェードアウト処理
    curGain += fadeDelta;
    if (curGain > 0) {
      out->SetGain(curGain);
    } else {
      fadeDelta = 0.0;
      wav->stop();
    }
  } else if (fadeDelta > 0) { // フェードイン処理
    curGain += fadeDelta;
    if (curGain < currentData.gain) {
      out->SetGain(curGain);
    } else {
      out->SetGain(currentData.gain);
      fadeDelta = 0.0;
    }
  }
}

void LoadTrack()
{
  LoadFile(currentData.wav, currentData.gain, currentData.triggerMode == TRIG_LOOP);
}

void SelectTrack(int index)
{
  if (!wav) { return; }
  if (wav->isRunning()) {
    Stop();
  }

  currentIndex = index;
  currentData = trackData[currentIndex];

  Serial.printf("SelectTrack:%X %s\r\n", currentData.dispNumber, currentData.name);

  if (currentData.triggerMode == TRIG_LOOP) {
    LoadTrack();
    FadePlay();
  }
}

void NextTrack()
{
  SelectTrack((currentIndex + 1) % TRACK_COUNT);
}

void PrevTrack()
{
  SelectTrack((currentIndex + TRACK_COUNT - 1) % TRACK_COUNT);
}

void LoadFile(const WavRef& ref, float gain, bool repeat)
{
  if (!wav) { return; }
  if (wav->isRunning()) {
    Stop();
  }

  delete file;
  file = new AudioFileSourcePROGMEM(ref.data, ref.size);
  if (!file) {
    Serial.printf("file ERROR!\r\n");
  }

  out->SetGain(gain);
  wav->Repeat = repeat;
}

void Play()
{
  if (wav->isRunning()) {
    return;
  }

  Serial.print("Play\r\n");
  bool result = wav->begin(file, out);
  if (!result) {
    isError = true;
    Serial.print("wav begin ERROR!\r\n");
  }
}

void Stop()
{
  Serial.print("Stop\r\n");
  wav->stop();
}

void FadePlay()
{
  Serial.print("FadePlay\r\n");
  curGain = 0.0;
  out->SetGain(curGain);
  bool result = wav->begin(file, out);
  if (!result) {
    isError = true;
    Serial.print("wav begin ERROR!\r\n");
  }
  fadeDelta = currentData.gain / FADEIN_STEP;
}

void FadeStop()
{
  Serial.print("FadeStop\r\n");
  curGain = currentData.gain;
  fadeDelta = -currentData.gain / FADEOUT_STEP;
}

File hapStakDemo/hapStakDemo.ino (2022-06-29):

/*
  hapStak DemoProgram
  version 0.1
  
  Copyright (C) 2021 Foster Electric Co., Ltd.


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
  You should have received a copy of the GNU General Public License
  along with this program.  If not, see <http://www.gnu.org/licenses/>.
*/

#include <M5Atom.h>
#include <math.h>

#include "FS.h"
#include "SPIFFS.h"

#include "AudioFileSourceSPIFFS.h"
#include "AudioFileSourceID3.h"
#include "AudioGeneratorWAVRepeatable.h"
#include "AudioOutputI2S.h"

//////////////////////////////////////////////////////////////////////////////////////////////////////////

#define FLG_WRITE_FILES 0 // 信号ファイルの書き込みを行うかどうか。信号ファイルを初めて書き込むときや変更したときは1、それ以外は0にする。

#define FILE_NAME "/file%02d.wav"  // 振動信号ファイルのファイル名。"%02d"に2桁でNo.が入る。先頭に"/"が必要。
#define BOOT_NAME "/boot.wav"  // 起動音ファイルのファイル名。先頭に"/"が必要。

const float DEFAULT_GAIN = 1.0; // 振動信号のデフォルトゲイン。0.0～1.0
const float BEEP_GAIN = 0.5; // Beep音、起動音のゲイン。0.0～1.0

const float ACCEL_THRESHOLD = 3.0;  // Swingトリガー時の閾値加速度[G]

const int INITIAL_DELAY = 0;  // 動作開始前のdelay値
const int LOOP_DELAY = 5; // メインループのdelay値

const int FADEIN_STEP = int(1000 / LOOP_DELAY); // フェードインのステップ数
const int FADEOUT_STEP = int(250 / LOOP_DELAY); // フェードアウトのステップ数

const long LONG_COUNT = int(300 / LOOP_DELAY);  // 長押しの反応時間
const long LONG_LONG_COUNT = int(900 / LOOP_DELAY); // 超長押しの反応時間
const long MULTI_COUNT = int(50 / LOOP_DELAY);  // ダブル・トリプルクリックの反応時間

//////////////////////////////////////////////////////////////////////////////////////////////////////////

typedef struct {
  int dispNumber;
  int fileNumber;
  int triggerMode;
  float gain;
  uint8_t dispColor[3];
} TrackData;

const int TRIG_LOOP = 0;
const int TRIG_BUTTON = 1;
const int TRIG_SWING = 2;

#define COLOR_BLACK { 0x00, 0x00, 0x00 }
#define COLOR_WHITE { 0xFF, 0xFF, 0xFF }
#define COLOR_RED { 0xFF, 0x00, 0x00 }
#define COLOR_GREEN { 0x00, 0xFF, 0x00 }
#define COLOR_BLUE { 0x00, 0x00, 0xFF }

const int BUTTON_FIRST = 0;
const int ACCEL_FIRST = 3;
const int LOOP_FIRST = 8;


const int TRACK_COUNT = 14; // 振動再生モード（トラック）の数

// トラックデータ
// LED表示の番号(0～F), 振動波形ファイルの番号, 駆動モードの種類, 再生ゲイン, LED表示色
TrackData trackData[TRACK_COUNT] = {
  // One Shot
  { 0x1, 7, TRIG_BUTTON, DEFAULT_GAIN, COLOR_RED }, // BUTTON_FIRST
  { 0x2, 8, TRIG_BUTTON, DEFAULT_GAIN, COLOR_RED }, 
  { 0x3, 9, TRIG_BUTTON, DEFAULT_GAIN, COLOR_RED },
  // Swing
  { 0x4, 10, TRIG_SWING, DEFAULT_GAIN, COLOR_GREEN }, // ACCEL_FIRST
  { 0x5, 11, TRIG_SWING, DEFAULT_GAIN, COLOR_GREEN },
  { 0x6, 12, TRIG_SWING, DEFAULT_GAIN, COLOR_GREEN },
  { 0x7, 13, TRIG_SWING, DEFAULT_GAIN, COLOR_GREEN },
  { 0x8, 14, TRIG_SWING, DEFAULT_GAIN, COLOR_GREEN },
  // Loop
  { 0x9, 1, TRIG_LOOP, DEFAULT_GAIN, COLOR_BLUE },  // LOOP_FIRST
  { 0xA, 2, TRIG_LOOP, DEFAULT_GAIN, COLOR_BLUE },
  { 0xB, 3, TRIG_LOOP, DEFAULT_GAIN, COLOR_BLUE },
  { 0xC, 4, TRIG_LOOP, DEFAULT_GAIN, COLOR_BLUE },
  { 0xD, 5, TRIG_LOOP, DEFAULT_GAIN, COLOR_BLUE },
  { 0xE, 6, TRIG_LOOP, DEFAULT_GAIN, COLOR_BLUE },
};

//////////////////////////////////////////////////////////////////////////////////////////////////////////

#define CONFIG_I2S_BCK_PIN      19
#define CONFIG_I2S_LRCK_PIN     33
#define CONFIG_I2S_DATA_PIN     22

AudioGeneratorWAVRepeatable *wav;
AudioFileSourceSPIFFS *file;
AudioOutputI2S *out;
AudioFileSourceID3 *id3;

int currentIndex = 0;
TrackData currentData;

double curGain = 0.0; // フェードイン・アウト時のゲイン
double fadeDelta = 0.0; // フェードイン・アウト時の変化量

bool isIMUInit = false;
bool isError = false;

//////////////////////////////////////////////////////////////////////////////////////////////////////////

void setup()
{
  M5.begin(true, false, true);
  delay(50);
  delay(INITIAL_DELAY);
  Serial.begin(115200);
  M5.dis.setWidthHeight(5, 5);    // add 2022.06.22 by B.T.O for M5Atom Library 0.0.5 or later
  Serial.printf("SPIFF init...\n");
  SPIFFS.begin();

  #if FLG_WRITE_FILES
  WriteFiles();
  #endif

  Serial.printf("WAV playback init...\n");

  audioLogger = &Serial;
  
  out = new AudioOutputI2S();
  out->SetPinout(CONFIG_I2S_BCK_PIN, CONFIG_I2S_LRCK_PIN, CONFIG_I2S_DATA_PIN);
  out->SetChannels(1);
  out->SetGain(DEFAULT_GAIN);
  if (!out) {
    isError = true;
    Serial.printf("I2S init FAILED!\n");
  }

  wav = new AudioGeneratorWAVRepeatable();
  if (!wav) {
    isError = true;
    Serial.printf("generator init FAILED!\n");
  }

  Serial.printf("IMU init...\n");

  if (M5.IMU.Init() != 0) {
    isIMUInit = true;
    Serial.printf("FAILED!\n");
  } else {
    isError = false;
    isIMUInit = true;
  }
  
  FillDisplay(0xFFFFFF);
  
  LoadFile(BOOT_NAME, BEEP_GAIN, false);
  Play();
  while (wav->loop()) { /*noop*/ }
  Stop();

  SelectTrack(0);
}

void loop()
{
  AudioLoop();
  ButtonLoop();
  AccelLoop();
  DisplayLoop();
  
  delay(LOOP_DELAY);
}

//////////////////////////////////////////////////////////////////////////////////////////////////////////

void ButtonLoop()
{
  static unsigned long pressCnt = 0;
  static unsigned long releaseCnt = ULONG_MAX;
  static int multiCnt = 0;

  M5.update();
  
  if (M5.Btn.isPressed()) {
    if (pressCnt < ULONG_MAX) {
      pressCnt ++;
    }

    if (pressCnt == 1) {
      SingleDown();  // 押したとき
    } else if (pressCnt == LONG_COUNT) {
      LongPress();
    } else if (pressCnt == LONG_LONG_COUNT) {
      LongLongPress();
    }

    releaseCnt = 0;
  } else {
    if (releaseCnt < ULONG_MAX) {
      releaseCnt ++;
    }

    if ((pressCnt > 0) && (pressCnt < LONG_COUNT)) {
      multiCnt ++;
    }
    
    if (releaseCnt == MULTI_COUNT) {
      if (multiCnt == 1) {
        SinglePress();  // 離したとき
      } else if (multiCnt == 2) {
        DoublePress();
      } else if (multiCnt >= 3) {
        TriplePress();
      }
      multiCnt = 0;
    }
    
    pressCnt = 0;
  }
}

void SingleDown() {
  if (currentData.triggerMode == TRIG_BUTTON) {
    LoadTrack();
    Play();
  }
}

void SinglePress() {
  if (currentData.triggerMode == TRIG_LOOP) {
    if (!(wav->isRunning())) {
      LoadTrack();
      FadePlay();
      //Play();
    } else {
      FadeStop();
      //Stop();
    }
  }
}

void DoublePress() {

}

void TriplePress() {
  SelectTrack(0);
}

void LongPress() {
  NextTrack();
}

void LongLongPress() {
  if (currentIndex < ACCEL_FIRST) {
    SelectTrack(ACCEL_FIRST);
  } else if (currentIndex < LOOP_FIRST) {
    SelectTrack(LOOP_FIRST);
  } else {
    SelectTrack(BUTTON_FIRST);
  }  
}

//////////////////////////////////////////////////////////////////////////////////////////////////////////

void DisplayLoop()
{
  static int num = -1;

  if (currentData.dispNumber != num) {
    DisplayNumber(currentData.dispNumber, currentData.dispColor);
    num = currentData.dispNumber;
  }
  
  DisplayState();
}
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

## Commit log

2021-09-21 Update README.md
    ブログ記事のURLを追加しました。
2021-10-03 Arduino MKRZERO用サンプル
2021-10-03 テスト用wavファイル
2021-10-03 ArduinoMKRZERO用サンプルプログラム(SDカード)
    SDカードのルートにあるSOUND.WAVファイルを鳴らす
2021-10-05 Update FAQ.md
    アナログ、デジタルを分離
2021-10-05 Update README.md
    構成変更
2021-10-05 Add files via upload
    回路図等アップロード
2021-10-05 Add files via upload
    筐体図追加
2021-10-10 .wavファイルから.cファイルへの変換ツール
    .wavファイルを.cのバイナリーファイルに変換するスクリプト入りhtmlファイル
2021-10-18 Add files via upload
    README追加
2021-10-18 Update README.md
    デジタル版基板画像追加
2021-10-31 Oculus Quest 2 取付用パーツ
    2.5mmのMDFから切り出してください。
    他に必要なもの
    M3 35mm ネジ x2
    木工用接着剤
2021-10-31 Oculus Quest 2 取付用パーツ 説明図
    Oculus Quest 2 取付用パーツ の組み立て説明図です。
2021-11-08 Update README.md
    MDFケースの簡易組立ガイドリンク追加
2022-05-10 Update README.md
    アナログ版 製品画像差し替え
2022-05-10 Update README.md
    アナログ端子情報更新
    アナログ仕様更新
2022-05-10 Update FAQ.md
    Q.モノラル音源とステレオ音源で振動に違いがありますかを追加
2022-06-29 Add files via upload
    一式更新
2022-11-10 回路更新反映
2023-02-15 発展的なデモ(ソース・3Dデータ配布) を追加

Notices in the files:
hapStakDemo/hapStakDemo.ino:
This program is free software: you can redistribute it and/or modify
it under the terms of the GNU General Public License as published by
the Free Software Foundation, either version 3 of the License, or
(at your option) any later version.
